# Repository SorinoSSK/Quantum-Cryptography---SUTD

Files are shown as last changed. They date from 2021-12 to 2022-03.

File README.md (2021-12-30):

# Quantum Cryptography
As networking technology advances, there has been an upsurge in demand for secure communication channels. Many important data have been transmitted across the network, and they must be encrypted to safeguard it. **Quantum Cryptography** is one of the techniques used to ensure that all of our communication channels are protected. This project uses the BB84 protocol to mimic Quantum Cryptography with an 8-bit encryption key.

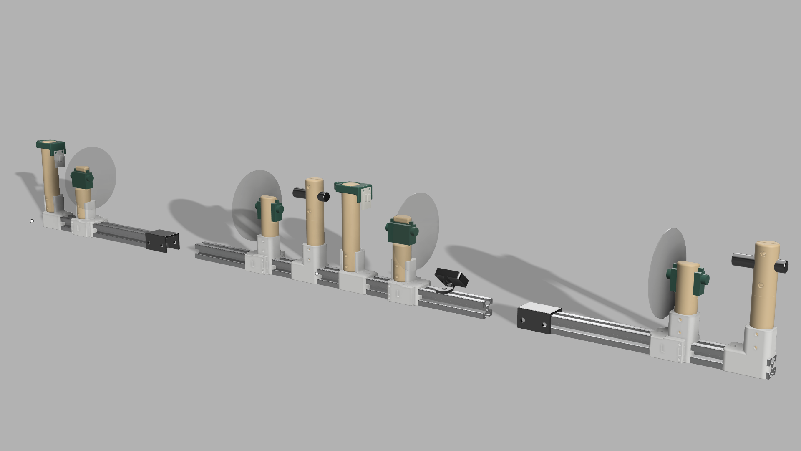
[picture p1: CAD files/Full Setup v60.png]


## Requirements notes
### Software
The structure is based on the use of three computers, notably Alice, Bob, and Eve, each of which controls a modular set. Arduino Mega is used to operate in each modules thus each computer requires the installation of Arduino IDE, https://www.arduino.cc/en/software. The project is tested and operated on Arduino IDE version 1.8.5.
### Hardware
Ensure that the laser's intensity is within the OPT101's operating range. In this project, the focused laser's maximum OPT101 readings in a closed room lab setting range from 570 to 650.
## Operation
### Step 1:
Link the modules together, either 
1) Alice and Bob
2) Alice, Eve and Bob where Eve is in between Alice and Bob
### Step 2:
Insert *charged* batteries into the battery case.
### Step 3:
Connect the Arduino Mega to a computer, 1 Arduino Mega is to be connected to a computer. All linear polariser should be rotated to stepper motor's 0 position upon the connection or start up of the Arduino Mega (Alice, Bob and Eve's program should have been uploaded into the Arduino Mega).
### Step 4:
Align the laser on Alice to the OPT101 on Bob. If Eve is connected, align the laser on Alice to the OPT101 on Eve and align the laser on Eve to the OPT101 on Bob. The focused laser should be fully within the black portion of OPT101 sensor.
### Step 5:
Open Arduino IDE on each computer controlling, Alice, Bob and Eve. To run the program, open Serial Monitor in the following order.
1) Alice or Eve
2) Bob
Bob's module is programmed to initiate the alignment of linear polariser thus it has to be reset last. (Opening Serial Monitor restarts the Arduino). The Serial Monitor button is a magnifying glass like button at the top right of the Arduino IDE.
### Step 6:
The project is split into 3 section:
1) Align Polariser
2) Bob initiate sending of encryption key 
3) 1. If the key Alice has matches with Bob, Alice and Bob will proceed to send message to one another. 
   2. If the key Alice has does not match with Bob, a prompt will appear in Bob's Serial Monitor to rebuild the key.

(Note: It is advisable to restart the whole process starting from polariser alignment. This is due to the difference in ambient light at different period of time. Ambient light can affect the light intensity reading when building the key). 
### Step 7:
Enjoy sending message over to each other! :)

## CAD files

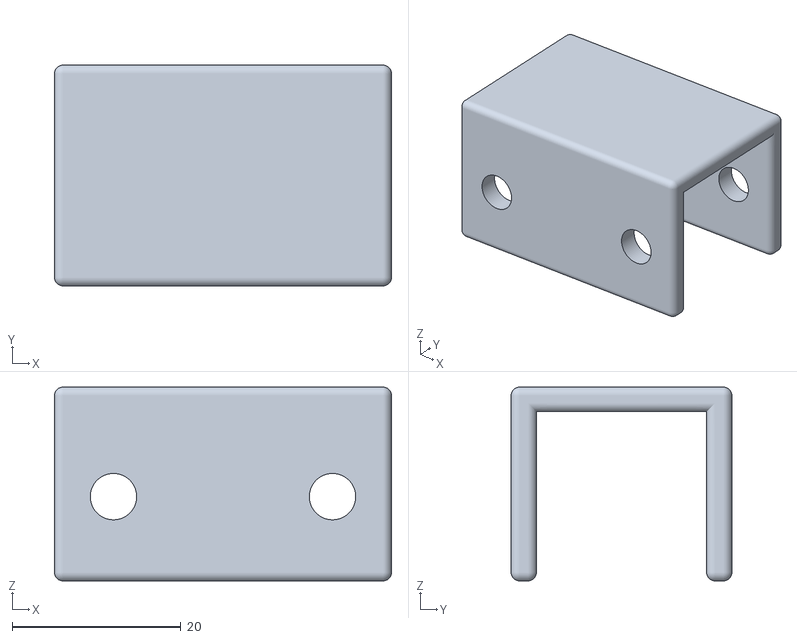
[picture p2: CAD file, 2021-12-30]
CAD files/Aluminium Profile Connector.stl
40.0 x 26.2 x 23.0

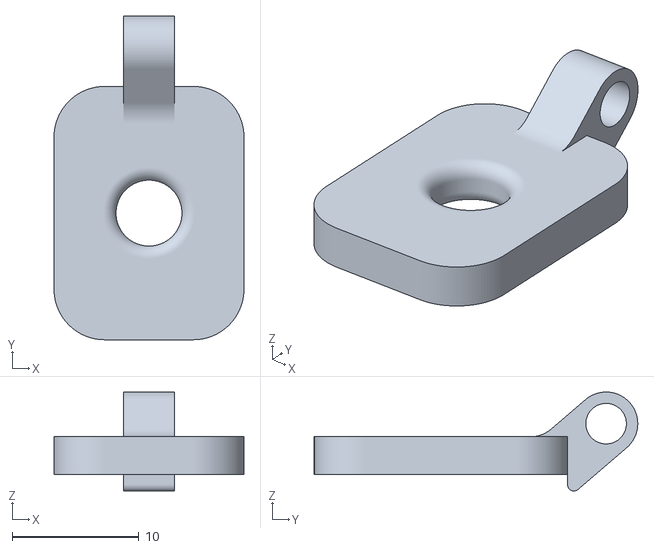
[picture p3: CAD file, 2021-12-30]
CAD files/IR Type 1/IR holder_Aluminium Extrusion.stl
15.0 x 25.5 x 7.81

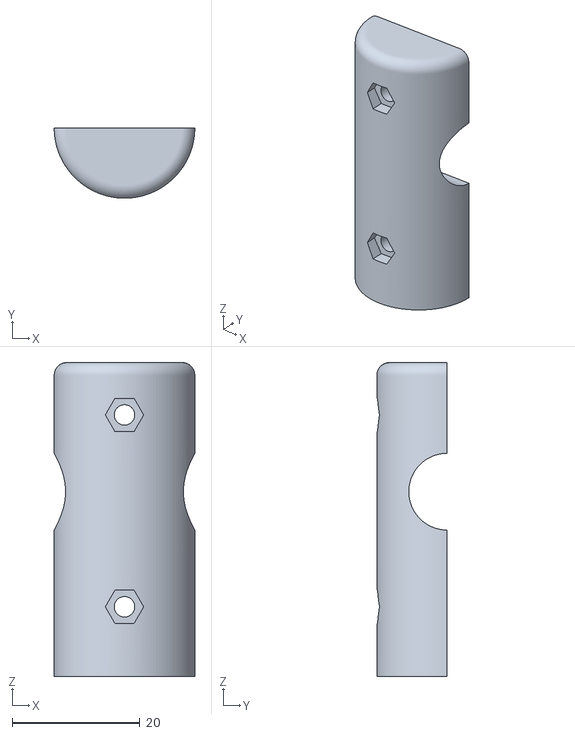
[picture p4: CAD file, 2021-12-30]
CAD files/Laser/Laser Clamp.stl
22.0 x 11.0 x 49.1

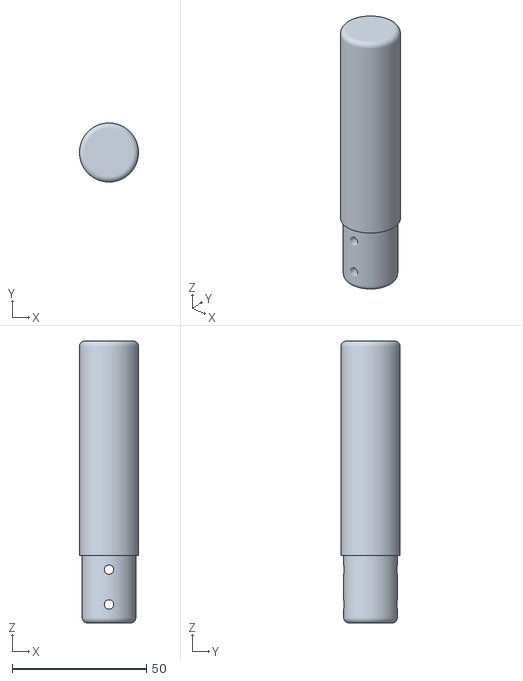
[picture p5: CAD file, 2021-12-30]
CAD files/OPT101/Rod for OPT101 Holder.stl
22.0 x 22.0 x 105.1

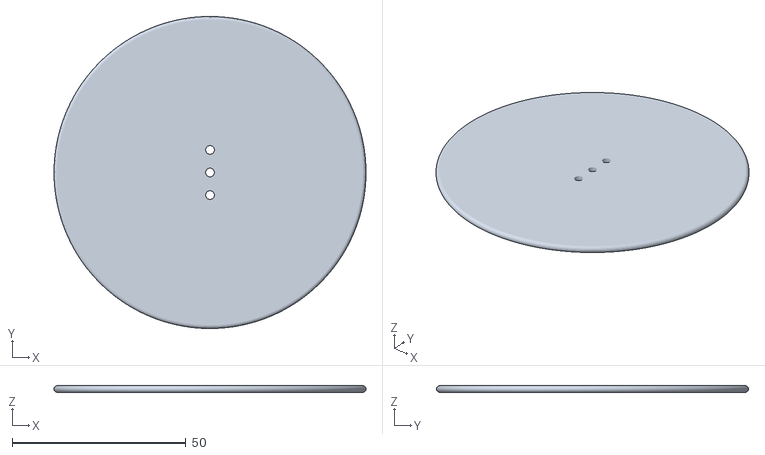
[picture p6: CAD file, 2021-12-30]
CAD files/Template/Linear Polariser Cut Template.stl
89.9 x 89.9 x 2.00

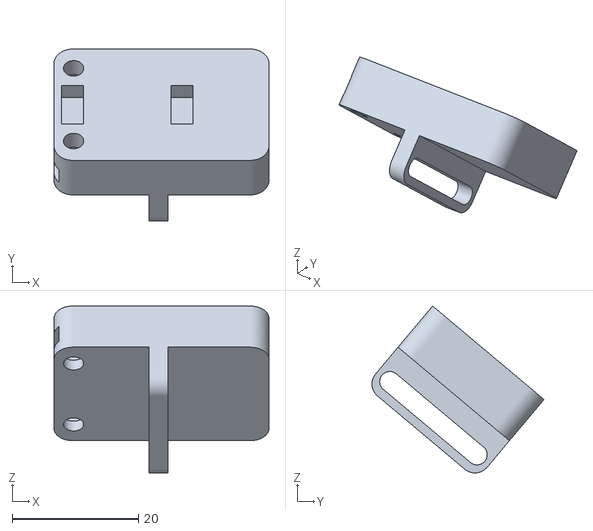
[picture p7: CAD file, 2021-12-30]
CAD files/IR Type 1/IR holder.stl
34.0 x 27.2 x 26.4

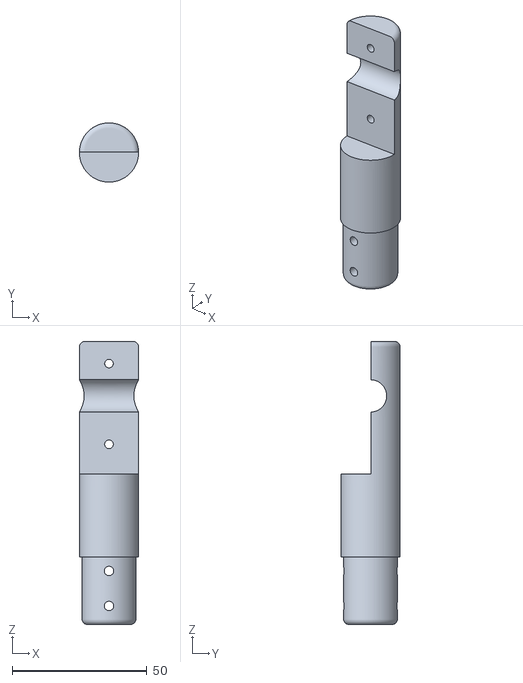
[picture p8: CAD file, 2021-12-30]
CAD files/Laser/Laser Rod.stl
22.0 x 22.0 x 105.1

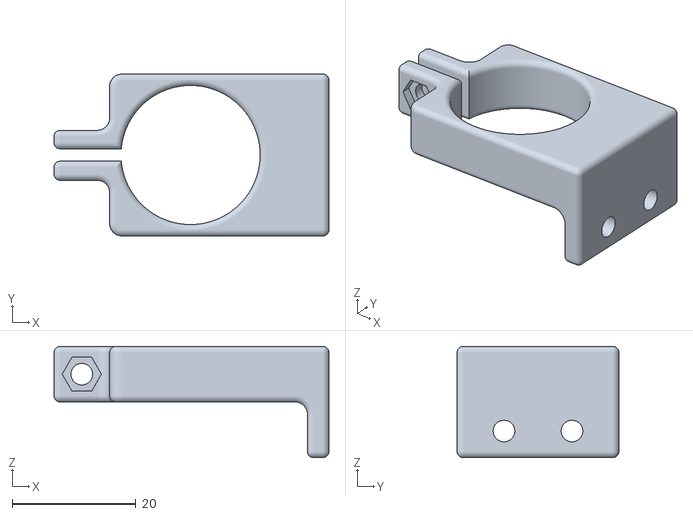
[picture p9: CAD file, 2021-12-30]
CAD files/OPT101/OPT101 Holder.stl
44.5 x 26.2 x 18.0

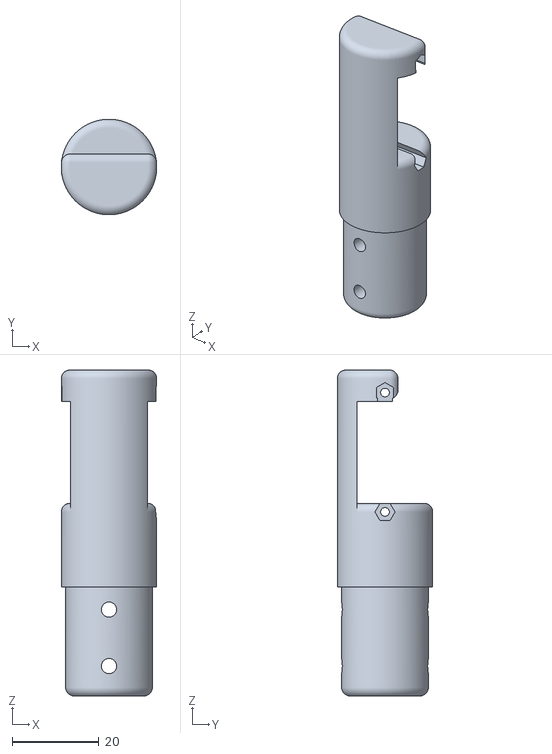
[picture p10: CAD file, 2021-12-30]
CAD files/Servo Motor Mount.stl
22.0 x 22.0 x 75.1

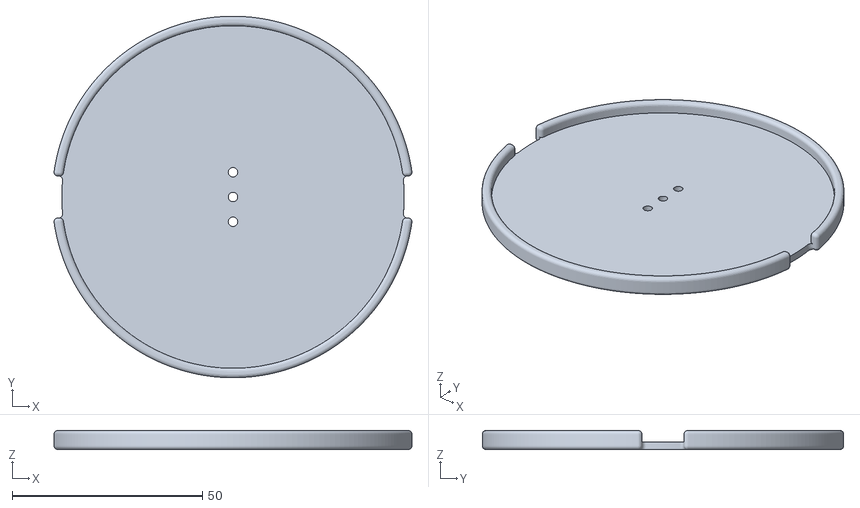
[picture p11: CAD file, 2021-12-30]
CAD files/Template/Linear Polariser Drill Template _ outer.stl
94.1 x 95.0 x 5.00

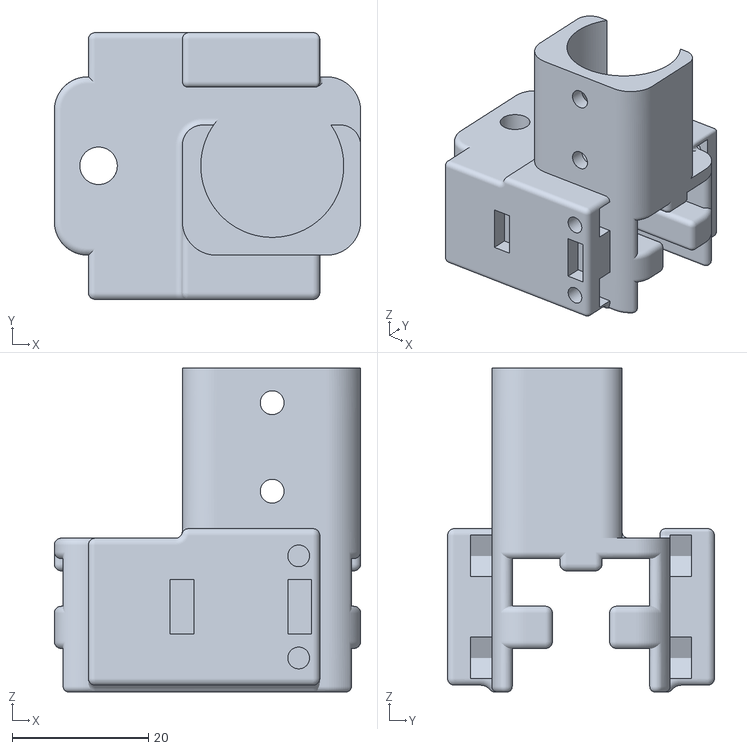
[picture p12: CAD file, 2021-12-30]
CAD files/Rail mount with IR holder for Aluminium Profile.stl
45.0 x 39.2 x 47.6

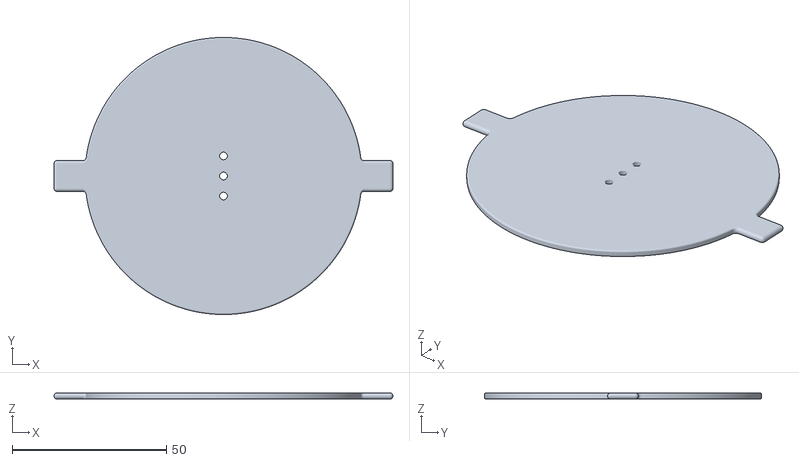
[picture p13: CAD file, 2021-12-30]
CAD files/Template/Linear Polariser Drill Template _ inner.stl
110.0 x 89.9 x 2.00

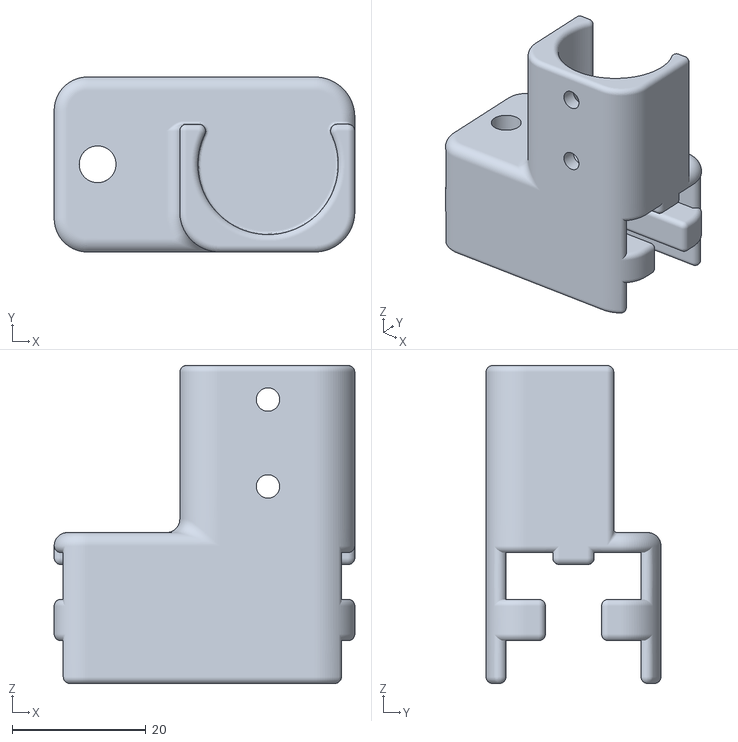
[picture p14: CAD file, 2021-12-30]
CAD files/Rail mount for Aluminium Profile.stl
45.0 x 26.2 x 47.6

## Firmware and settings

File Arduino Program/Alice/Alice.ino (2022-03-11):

/* Program written by Seow Sin Kiat in collaboration of Ivan Feng
  * Credit of randomisation function is have to be given to user, aarg.
 */
 /* Code Representation ver 2
  * 691139 - Sensor has completed setup.
  * 691140 - Laser Tranmitter has completed setup.
  * 691141 - Laser Receiver completed 180 degree light check.
  *        - rotate to check for next basis.
  * 691142 - Feedback Transmitter moved on request.
  * 691143 - Laser receiver recorded ambience value for offset.
  * 691144 - Begin Quantum Crypto transmission.
  * 691145 - Bob request to send Alice data.
  * 691146 - Alice stating validation key is correct.
  * 691147 - Alice stating validation key is wrong.
  * 691148 - Timeout request for last sent data.
  * 691149 - After timeout indication for Serial Monitor to inform Bob on the start of sending encrypted message. 
  *        - (no more characters received, String is read character by character)
  * 691150 - Bob acknowledge acknowledge the sending of encrypted message and reply.
  * 691151 - Alice inform Bob that there is no error in the character he receive.
  * 691152 - Alice inform Bob that there is error in the character he receive.
  * 691153 - Alice inform Bob that the full message have been sent.
  * 691154 - After timeout indication for Serial Monitor to inform Alice on the start of sending encrypted message. 
  *        - (no more characters received, String is read character by character)
  * 691155 - Alice acknowledge the sending of encrypted message and reply.
  * 691156 - Bob inform Alice that there is no error in the character he receive.
  * 691157 - Bob inform Alice that there is error in the character he receive.
  * 691158 - Bob inform Alice that the full message have been sent.
  * 
  * Functions
  * getRandomSeed()                   - Return randomised seed values from noise voltage
  * Time()                            - Return waited time
  * Time(Long)                        - Return True/False of time reached
  * RecordTimer()                     - Records new timestamp
  * sendIRData(String, String, Long)  - Set data to be sent later
  * sendIRData()                      - Sends data through IR with preset data
  * enableIR()                        - Enable IR after time reached 100
  * resetTask()                       - Reset task values
  * TaskTimer()                       - Return task's waited time
  * TaskTimer(Long)                   - Return True/False of task's time reached
  * RecordTaskTimer()                 - Records new task timestamp
  * timeOut()                         - Count for timeout and activate timeout sequence
  * input(char IVal)                  - Process Serial Monitor input (Start command or sending text to Bob)
  * BinaryConverter(String Val)       - Convert String received from IR to Binary and store as long
  * EncryptValue(char Val)            - XOR Encryption
  * resetIR()                         - Clear IR transmission values and state
  * resetKey()                        - Clear encryption key built and state
  * 
  * After Value 100022 require more than 500ms
  */

/*----- Libraries -----*/
#include <Servo.h>
#include <Console.h>
#include <IRLibAll.h>
#include <IRLib_P01_NEC.h>
#include <IRLibDecodeBase.h>
#include <IRLibCombo.h>

/*----- Pins -----*/
int Laser = 4;                            // Pin for Laser        (Can be any pin)    **Can be edited**
int Motor = 6;                            // Pin for Servo motor  (Require PWM)       **Can be edited**
int LED   = 13;                           // Pin for LED checker  (Can be ignored)    **Can be edited**
IRrecvPCI myReceiver(2);                  // Receiver connected to pin 2
                                          // Transmitter pin 3 for uno and pin 9 for mega
/*----- Task Oriented -----*/
long    TimeRec     = 0;                  // Main timer
long    TaskTimeRec = 0;                  // Task timer
bool    EnReceiver  = false;              // CHECKER for enabling IR receiver
bool    KeyBuilt    = false;              // CHECKER for key sent.
String  LastTask    = "";                 // STORE task
String  val         = "";                 // STORE IR transmission value
String  type        = "";                 // STORE IR transmission type 
long    ms          = 0;                  // SET   IR transmission delay
long    msTask      = 0;                  // SET   task delay
int     Loop        = 0;                  // Main loop count
bool    idle        = true;               // Disable timeout (Controller forced to idle)
long    msTimeOut   = 3000;               // SET  timeout time                        **Can be edited**
String  LastVal     = "";                 // STORE last IR transmission value
String  LastType    = "";                 // STORE last IR transmission type
String  msg         = "";                 // STORE message string

/*----- Position -----*/
int BiasesPos[4]    = {0,90,45,135};

//Checker
bool    LightRdy    = true;               // Force receiver to be able to activate this only once
bool    StartEn     = false;              // Force Quantum channel to activate with this on true
bool    Printing    = false;               // Disable to remove debugging prints       **Can be edited**
bool    Sending     = false;              // Force rotation of linear polariser activation
bool    ValiCheck   = false;              // Force system to check validation key.
bool    Commu       = false;              // Timeout to get last character of message sent
bool    MsgChannel  = false;              // Enable timeout for sending message
bool    Msg2Channel = false;              // Force system to check validity of last message sent
bool    BobTalking  = false;              // Check if Bob is sending any message

/*----- Key -----*/
int     State     = 0;                    // Store the last state of linear polariser
String  EncryKey  = "";                   // To build encryption key
String  ValiKey   = "";                   // Sacrificical bits to check with Bob
String  PValiKey  = "";                   // For printing only

/*----- Instances -----*/
Servo     BiasStepper;                    // Create Servo object
IRsend    mySender;                       // Create IR transmitter object
IRdecode  myDecoder;                      // Create decoder object

void setup()
{
    Serial.begin(9600);                                       // Begin serial communication
    pinMode(Laser, OUTPUT);                                   // Set pin for laser to output
    pinMode(LED,OUTPUT);                                      // Set onboard LED to output (For visual verification that IR is working)
    BiasStepper.attach(Motor);                                // Set pint for servo
    BiasStepper.write(0);                                     // Set servo to position 0 (0 to 180 degrees)
    digitalWrite(Laser, HIGH);                                // Set Laser to be turned on on default
    randomSeed(getRandomSeed());                              // Generate random seed with stray voltage from analog read
    if (Printing)
      Serial.println("Debugging mode is enabled.");
    else
      Serial.println("Debugging mode is disabled.");
    Serial.println("System initialised, waiting for Bob to be ready.");
    mySender.send(NEC, 691140, 38);                           // To indicate laser is turned on
    TimeRec = millis();                                       // Initialise timestamp
    EnReceiver = true;                                        // Enable receiver in 100ms
}

/*----- Program flow -----*/
/* 1) Send data through IR if available
 * 2) Enable IR receiver in 100ms if enabled
 * 3) Read and perfomer task if IR receiver received data
 * 4) Perform task if enabled
 * 5) Timeout of required
*/
void loop()
{
    sendIRData();                                     // Send IR data
    enableIR();                                       // Enable IR receiver
    if (myReceiver.getResults())                      // IR receiver's message
    {
        myDecoder.decode();
        if (Printing && myDecoder.value != 0)         // To debug on IR data received and the timing it received
        {
            Serial.print("--+ IR Checker received ");
            Serial.print(myDecoder.value);
            Serial.print(", ");
            Serial.print(Time());
            Serial.println("ms after IR is enabled.");
        }
        switch (myDecoder.value)
        {
            case 0:                                   // Ignore if receiver received 0, interferred data read by IR receiver will be read as 0.
                myReceiver.enableIRIn();
                if (Printing)
                    Serial.println("--+ Received 0, re-enabling IR receiver due to stray signal.");
                break;
            case 691139:                              // Alice informing Bob that her photosensor is ready.
                if (LightRdy)                         // Alice can only inform Bob to start once.
                {
                    sendIRData("691140", "long", 150);    // Bob giving feedback to start calibration.
                    RecordTimer();                        // Reset timer to send data
                    LightRdy = false;                     // Disable 691139
                    Serial.println("Bob has indicated ready, begin intensity calibration.");
                }
                break;
            case 691141:                              // Alice requesting bob to rotate linear polariser to the next base.
                LastTask = "StepperChecker";              // Set task to be worked on
                msTask = 0;                               // Set delay for task
                RecordTaskTimer();                        // Reset timer for task
                idle = false;                             // Enable time out
                break;
            case 691143:                              // Alice informing Bob that calibration is completed.
                Serial.println("-----------------------------");
                Serial.println("System and light intensity calibration has completed.");     // Printing
                Serial.println("Key in 's' or 'S' to begin quantum key generation.");
                Serial.println("-----------------------------");
                StartEn = true;                                           // Enable reading of data.
                break;
            case 691145:                              // Alice's start byte to send validation bits 
                ValiCheck = true;                           // Set task to verify validation bits
                EnReceiver = true;                          // Enable IR receiver in 100ms
                RecordTimer();                              // Reset timer for IR to start
                break;
            case 691148:                              // Timeout received from Bob
                if (Printing)
                    Serial.println("--+ Time out received!");
                sendIRData(LastVal, LastType, 500);         // Send last value and type sent.
                RecordTimer();                              // Reset timer for sending.
                break;
            case 691150:                              // Alice's reply from Bob's request to send encrypted message.
                LastTask = "Communication";                 // Set task to communication mode
                msTask = 300;                               // Set task delay to 300ms
                RecordTaskTimer();                          // Reset task timer
                break; 
            case 691154:                              // Bob request to send Alice message
                Serial.println("(Listening to Bob. Console closed)");       // 
                sendIRData("691155", "long", 500);          // Reply Bob to send the message.
                RecordTimer();                              // Reset timer to send message
                BobTalking = true;                          // Force system to be reading from Bob
                StartEn = false;                            // Disable Serial Com
                break;
            case 691156:                              // Bob informing Alice that the message he received is correct.
                if(LastVal != "691155")
                {
                    if(Printing)
                    {
                        Serial.print("Bob sent: ");
                        Serial.print(LastVal.toInt());
                        Serial.print(" decipher to: ");
                        Serial.println(char(LastVal.toInt()^BinaryConverter(EncryKey)));
                    }
                    msg += char(LastVal.toInt()^BinaryConverter(EncryKey));
                    sendIRData("691155", "long", 500);      // Replying Bob to send the next character
                }
                RecordTimer();                              // Reset timer to send message
                break;
            case 691157:                              // Bob informing Alice that the message he received is incorrect.
                EnReceiver = true;                          // Do nothing and wait for message
                RecordTimer();                              // Reset timer to enable receiver
                break;
            case 691158:                              // Bob informing Alice that he have finish sending his messages.
                Serial.print("Bob: ");
                Serial.println(msg);
                EnReceiver = true;                          // Enable receiver after 100ms  
                msg = "";                                   // Reset message string
                StartEn = true;                             // Enable Serial Com input
                BobTalking = false;                         // Reset listening to bob
                break;
            default:                                  // Any other data that is not filtered
                if (EncryKey.length() < 16 && !KeyBuilt)    // if building encryption key
                {
                    int Bases = 2;                          // Init Base state to |psi>
                    String DataToSend = "1";                // Init data state to 1
                    Sending = true;                         // Enable sending for data
                    if (State == 0 || State == 1)           // if state is not in base |psi>
                        Bases = 1;                          // change base to |phi>
                    if (myDecoder.value == Bases)           // if Bob has the same base as Alice
                    {
                        DataToSend = "2";                   // reply acknowledgement
                        if (State == 0 or State == 2)       // check for the state in the base
                            EncryKey += String(1);
                        else
                            EncryKey += String(0);
                        if (EncryKey.length() == 16)        // If key is fully built
                        {
                            Serial.println("⥬ Key length reached!");
                            Sending = false;                // Disable sending
                            LastTask = "Validation";        // Change task to validation mode
                            msTask = 0;                     // Reset task delay to 0
                            RecordTaskTimer();              // Reset task timer
                            KeyBuilt = true;                // Record key is built
                        }
                        Serial.println(", Basis matched.");
                        Serial.print("Agreed Key: ");
                        Serial.println(EncryKey);           // Prints key while it builds
                    }
                    else if (myDecoder.value != Bases)
                    {
                      Serial.println(", Basis mismatched.");
                    }
                    sendIRData(DataToSend, "int", 500);     // Send key info through IR to Bob
                    RecordTimer();                          // Reset IR transmission timer
                }
                else if (ValiCheck)                         // If program finish building of key and enter validation check
                {
                    String returnVal = "691147";            // Init code to be sent to Bob (Validation key is wrong)
                    if (myDecoder.value == ValiKey.toInt()) // If validation key matches Bob
                    {
                        returnVal = "691146";               // Change code to be sent to Bob (Validation key is correct)
                        Serial.println("Validation key matched!");
                        Serial.println("Communication channel is open. Type your message below.");
                    }
                    else                                    // Prompt to restart building key
                    {
                        Serial.println("Validation key does not match!");
                        Serial.println("-----------------------------");
                        Serial.println("Incorrect key!");   // Printing
                        Serial.println("Key in 's' or 'S' to restart.");
                        Serial.println("-----------------------------");
                        resetKey();                         // Reset key built
                        resetIR();                          // Reset IR values
                    }
                    StartEn = true;                         // Enable reading of data.
                    idle = true;                            // Enable device idling (Disable timeout)
                    ValiCheck = false;                      // End Validation mode
                    sendIRData(returnVal, "int", 1000);     // Send IR value to Bob
                }
                else if (Msg2Channel)                       // If sending message to Bob (Validation key matches)
                {
                    if(Printing)                            // If printing is enabled (for debugging)
                    {
                      Serial.print("Last Value: ");
                      Serial.print(LastVal);
                      Serial.print(", comparing to received value: ");
                      Serial.println(myDecoder.value);
                    }
                    if (LastVal == String(myDecoder.value)) // If sent value matches Bob's reply
                    {
                        if(Printing)                        // If printing is enabled (for debugging)
                            Serial.println("--+ Last character sent matches.");
                        sendIRData("691151", "long", 200);  // Send code to Bob to inform him to receive next byte of the message.
                    }
                    else                                    // Else error occur in the message sent to Bob.
                    {
                        if(Printing)                        // If printing is enabled (for debugging)
                            Serial.println("--+ Last character sent does not match.");
                        sendIRData(LastVal, "long", 50);    // Resend message sent to Bob
                    }
                    Msg2Channel = false;                    // Turn off message sending mode
                }
                else if(BobTalking)                         // If Bob is sending message to Alice
                {
                    sendIRData(String(myDecoder.value), "long", 500); // Reply Bob on whatever he send
                    RecordTimer();                          // Reset IR transmission delay timer
                }
                break;
        }
    }
    else if (Serial.available() > 0)                        // If Serial Monitor receive input
    {
        input(Serial.read());                               // Transfer input received to function and to be processed
    }
    if (LastTask != "" && TaskTime(msTask))                 // If there are still task to be performed and delay have been reached
    {
        if (LastTask == "StepperChecker")                   // Check if task is stepper motor's movement
        {
            if (Loop == 0)                                  // If linear polariser is performing 1st stage synchronisation check
            {
                msTask = 700;                               // Set task delay (wait for servo motor to finish moving)
                BiasStepper.write(BiasesPos[2]);            // Set stepper motor to 1st stage position
                sendIRData("691142", "long", 200);          // Inform Bob that 1st stage position check is completed
                idle = true;                                // Enable Idling (Disable IR transmission time out)
            }
            else if (Loop == 1)                             // If linear polariser is performing 2nd stage synchronisation check
            {
                resetTask();                                // Reset Task
            }
            RecordTimer();                                  // Reset IR transmission delay
            RecordTaskTimer();                              // Reset Task delay
        }
        else if (LastTask == "Sending" && Sending)          // If Task is on key value comparison. (Compare laser's base)
        {
            int RandoVal = random(4);                       // Get random integer from a range of 0-3
            Serial.print("⟹ State: ");
            int Bias = BiasesPos[RandoVal];                 // Retrieve position angle with the given random integer
            BiasStepper.write(Bias);                        // Write position to servo
            if (Printing)
              Serial.println(RandoVal);
            else
            {
              if (RandoVal == 0)
              {
                Serial.print("|V〉");  
              }
              else if (RandoVal == 1)
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

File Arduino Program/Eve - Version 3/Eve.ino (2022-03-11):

 /* Code Representation 2
  * 691139 - Sensor has completed setup
  * 691140 - Laser Tranmitter has completed setup
  * 691141 - Laser Receiver completed 180 degree light check
  *        - rotate to check for next basis
  * 691142 - Feedback Transmitter moved on request 
  * 691143 - Laser receiver recorded ambience value for offset   
  * 691144 - Begin Quantum Crypto transmission
  * 691145 - Bob request to send Alice data
  * 691146 - Alice stating validation key is correct
  * 691147 - Alice stating validation key is wrong
  * 691148 - Timeout request for last sent data.
  * 
  * Functions
  * getRandomSeed()                   - Return randomised seed values from noise voltage
  * Time()                            - Return waited time
  * Time(Long)                        - Return True/False of time reached
  * RecordTimer()                     - Records new timestamp
  * sendIRData(String, String, Long)  - Set data to be sent later
  * sendIRData()                      - Sends data through IR with preset data
  * enableIR()                        - Enable IR after time reached 100
  * resetTask()                       - Reset task values
  * TaskTimer()                       - Return task's waited time
  * TaskTimer(Long)                   - Return True/False of task's time reached
  * RecordTaskTimer()                 - Records new task timestamp
  * timeOut()                         - Count for timeout and activate timeout sequence
  * 
  * After Value 100022 require more than 500ms
  */
#include <Servo.h>
#include "IRLibAll.h" //library for IR
#include <IRLib_P01_NEC.h>
#include <IRLibDecodeBase.h>
#include <IRLibCombo.h>
#include <string.h>

//Pins
int Sense = A3;                     // Pin for OPT101         (Can be any pin)    **Can be edited**
int MotorA = 6;                      // Pin for Servo motor    (Require PWM)       **Can be edited**
int MotorB = 5;                      // Pin for Servo motor    (Require PWM)       **Can be edited**
int Laser = 4;
IRrecvPCI myReceiver(2);            // Receiver connected to pin 2
                                    // Transmitter pin 3 for uno and pin 9 for mega
//Position                  
int BiasesPos[4]  = {0,0,0,0};      // STORE state position
int BiasesVal[4]  = {0,0,0,0};      // STORE state intensity value

int BiasesPosA[4]  = {0,90,45,135};      // STORE state position

//For Data Collection
int Data[16];                       //array to store the measurement for the 30 measurements
int index = 0;                      //Use multiple times for counting
int cut   = 0;                      //The cut off to decide if it is a high or a low
int angle = 0;

//Checker Variable
int     taskTracker = -1;           //Too track of the task
bool    Printing    = false;        //To swtich between detailed printing and less printing

// Variables for Key
long   Cipher_Key      = 0;         //Encrytion Key

// Variables for timer
long    TimeRec     = 0;                  // Main timer
long    TaskTimeRec = 0;                  // Task timer
bool    EnReceiver  = false;              // CHECKER for enabling IR receiver
String  val         = "";                 // STORE IR transmission value
String  type        = "";                 // STORE IR transmission type 
long    ms          = 0;                  // SET   IR transmission delay
long    msTask      = 0;                  // SET   task delay
bool    idle        = true;               // Disable timeout (Controller forced to idle)
long    msTimeOut   = 3000;               // SET  timeout time            **Can be edited**
String  LastVal     = "";                 // STORE last IR transmission value
String  LastType    = "";                 // STORE last IR transmission type
bool MsgChannel = true;                   //For timeout

// For Users input
String Message = "";                      //For Alice message
bool AliceTalking = false;                //To take note that Alice is talking

String myMessage = "";                    //For Bob's messsage
bool BobTalking = false;                  //To take note that Bob is talking
int TextLength = 0;                       //To check how many characters are to be sent
int sendIndex = 0;                        //To keep track of the current charcater position

//Instances
Servo     BiasStepperA;
Servo     BiasStepperB;
IRsend    mySender;
IRdecode  myDecoder;                      //create a decoder object  

void setup() 
{
    Serial.begin(9600);
    pinMode(Sense, INPUT);
    BiasStepperA.attach(MotorA);
    BiasStepperA.write(0);
    BiasStepperB.attach(MotorB);
    BiasStepperB.write(0);
    randomSeed(getRandomSeed());
    if (Printing){
      Serial.println("Debugging mode is enabled");
    }
    else {
      Serial.println("Debugging mode is disabled");
    }
    pinMode(Laser, OUTPUT);
    digitalWrite(Laser, HIGH);
    Serial.println("System initialised. Listening to Classical Channel.");
    myReceiver.enableIRIn();
    
}
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

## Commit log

2022-03-11 Update Printing Format
2022-03-11 Rename Arduino Program/Bob - Version 7/Bob.ino to Arduino Program/Bob - Version 8/Bob.ino
2022-03-11 Rename Arduino Program/Alice/Alice.ino to Arduino Program/Alice - Version 15/Alice.ino
2022-03-11 Update Pretty Printing with State Prediction
2022-03-11 Pretty Printing update
